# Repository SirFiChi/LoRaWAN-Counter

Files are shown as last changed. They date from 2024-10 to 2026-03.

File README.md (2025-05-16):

# LoRaWAN-Counter V1.0
Digitaler Zutrittszähler für die Statistik der Münchner Stadtbibliothek
und für den digitalen Zwilling der LHM

Bei diesem Projekt handelt es sich um eine kostengünstige Lösung einfache Daten per LoRaWAN an das TTN zu senden, um diese für andere Dienste, in diesem Fall den digitalen Zwilling der LHM, bereitstellen zu können.

Als Pilotprojekt dient die bereits "analoge" Zählung der Besucher*Innen der Münchner Stadtbibliotheken. Diese werden mit einer Lichtschranke und einem Zählwerk erfasst. Um die Daten nicht ablesen und manuell übermitteln zu müssen, soll eine einfache technische Lösung umgesetzt werden, die den Einsatz des Personals ablöst.

---
## Ablauf
Der geplante Ablauf des Codes:

* Initialisierung der Komponenten
* Abfrage ob Jumper gesetzt sind (für Dividierung z.B. durch zwei, wenn Eingang gleich Ausgan, oder durch vier, wenn die Lichtschranke zu Tief hängt und Beine und nicht Hüften zählt. Ggf. auch einen Verbose Modus für das Display, um z.B. Signalstärke zu messen).
* Zugriff auf Speicher ob bereits ein Wert gespeichert wurde und zu diesem addieren.
* Zählen der Auslösungen an der Lichtschranke.
* Übermitteln der Daten alle X Minuten an das TTN. (Ggf. auch per Jumper anpassbar. Im Fall der MSB ist alle sechs Minuten angedacht.)

---
## Hardware
* Microcontroller: Basis ist ein "ESP32 LoRa V3" mit SX1262 Chip (863-928MHz) als Original der Firma Heltec oder rebranded.
* Gehäuse: Die Firma Mollom bietet absperrbare Gehäuse, die zwar keinen 100%igen Schutz vor Manipulation bieten, aber die Komponenten schützen und Manipulation sichtbar machen.
* Daten-Speicher:interner Speicher ades ESP32

Für einen Prototypen werden folgende Komponenten getestet:
* https://www.amazon.de/gp/product/B0CKRGVLK4 (ESP32 LoRa V3)
* https://www.amazon.de/gp/product/B09XJZ6WGT (Gehäuse)
* https://www.amazon.de/gp/product/B077JYCD18 (Lichtschranke)
* https://www.amazon.de/gp/product/B07BDTMZQ6 (Netzteil 5V/3A)
* https://www.amazon.de/gp/product/B06XWSYRCF (Netzteil 12V/1,25A)
* https://www.amazon.de/gp/product/B0CYLPM7T7 (Kabeldurchführungen)
* ESP32-Hutschienen-Gehäuse für den ESP32 ist eine Eigenentwicklung

---
## Software
* Es wird die Arduino IDE verwendet, um einen einfachen Einstieg zu gewährleisten, um auf mehr Ressourcen zugreifen zu können und um das Projekt möglichst einfach reproduzierbar zu machen.
* In den Dateien wird auf die Herkunft von Fremdcode hingewiesen.
* Um den Versand alle X Minuten durchzuführen, während die Zählung weiterläuft, wurde das Skript LoRaWAN_TTN.ino von Rop Gonggrijp (ropg) und mein erster Versuch gekreuzt
* Ich bin kein Software-Entwickler. Was nach "Quick'n'Dirty" aussieht ist nur Dirty. Verbesserungsvorschläge werden gerne angenommen.

---
## Sicherheit
* Als Übertragungsmittel wurde LoRaWAN gewählt, damit die Datenübertragung nicht durch die Infrastruktur der LHM läuft. Die Daten werden an das TTN übermittelt, und dort abgegriffen.
* Die übertragenen Daten sind "Referat", "DeviceID", "Teiler" des Messwertes, "Zähler1", "Zähler2" und den "Gesamtzähler" (die Addition der beiden Zähler). Es werden also keine personenbezogennen oder sicherheitsrelevanten Daten übermittelt!
* Durch die sehr geringe Relevanz der Datensicherheit ist eine unverschlüsselte Datenübertragung zu einem Drittanbieter nicht von Bedeutung.
* Auch wenn der Quellcode über GitHub veröffentlicht wurde, ist eine Manipulation der Daten am Sender erst möglich, wenn der Mikrokontroller entwendet wird. Die Zugangsdaten zum TTN (AppEUI, DevEUI, DEVKEY) müssen hierfür ausgelesen werden.
* Der Sender selbst wird in einem absperrbaren Gehäuse verbaut. Manipulation am Gehäuse wird wahrgenommen.

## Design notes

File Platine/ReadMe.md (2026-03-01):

Gedruckte Platine für den LoRaWAN-Counter in einem neuen, eigenständigen Gehäuse.
J1 - Impulsgeber 1
J2 - Impulsgeber 2
J3 - Jumper für Teilung und Reset (Ohne = 1:1 || 1+2 = 1/2 || 2+3 = 1/4 || 1+2+3 = Reset)
J4 - 5V | 3.3V | Ground

Screenshots & Gerber-Datei für https://jlcpcb.com

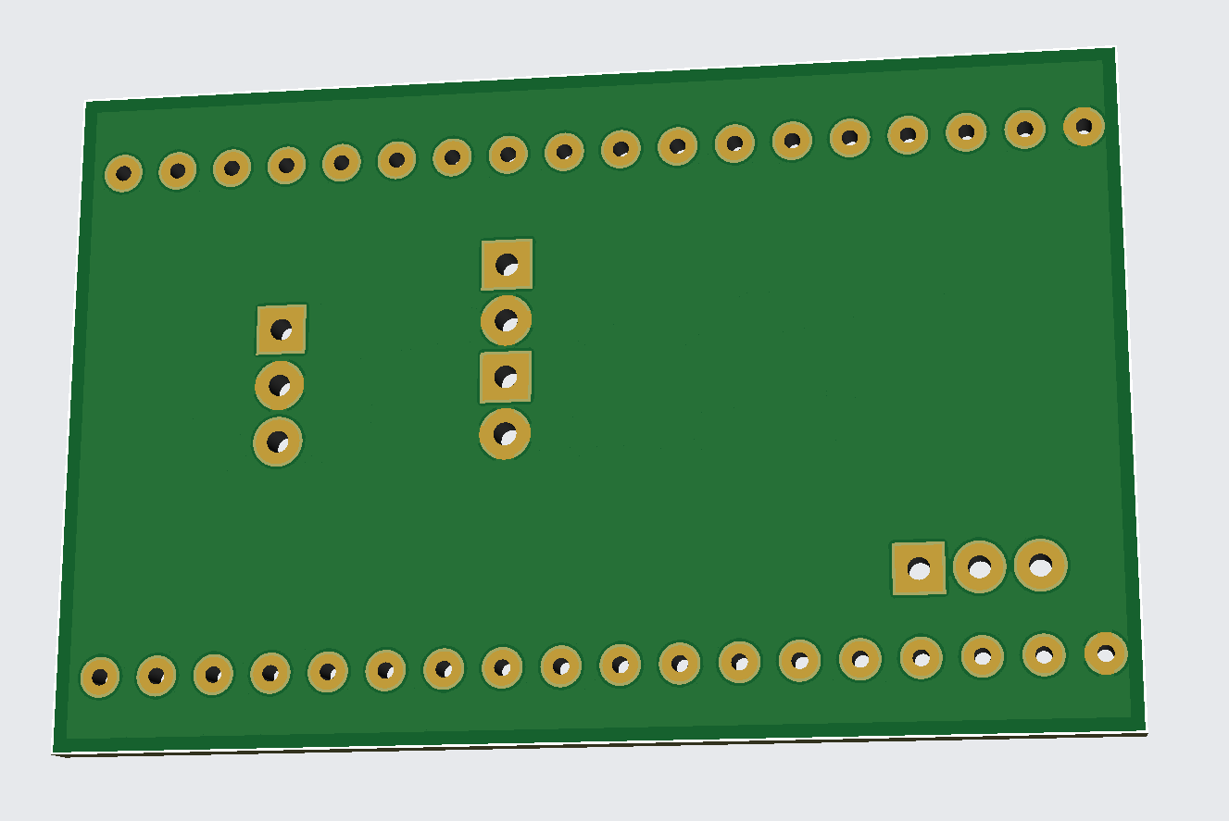
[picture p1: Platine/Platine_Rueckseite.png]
Platine Rückseite


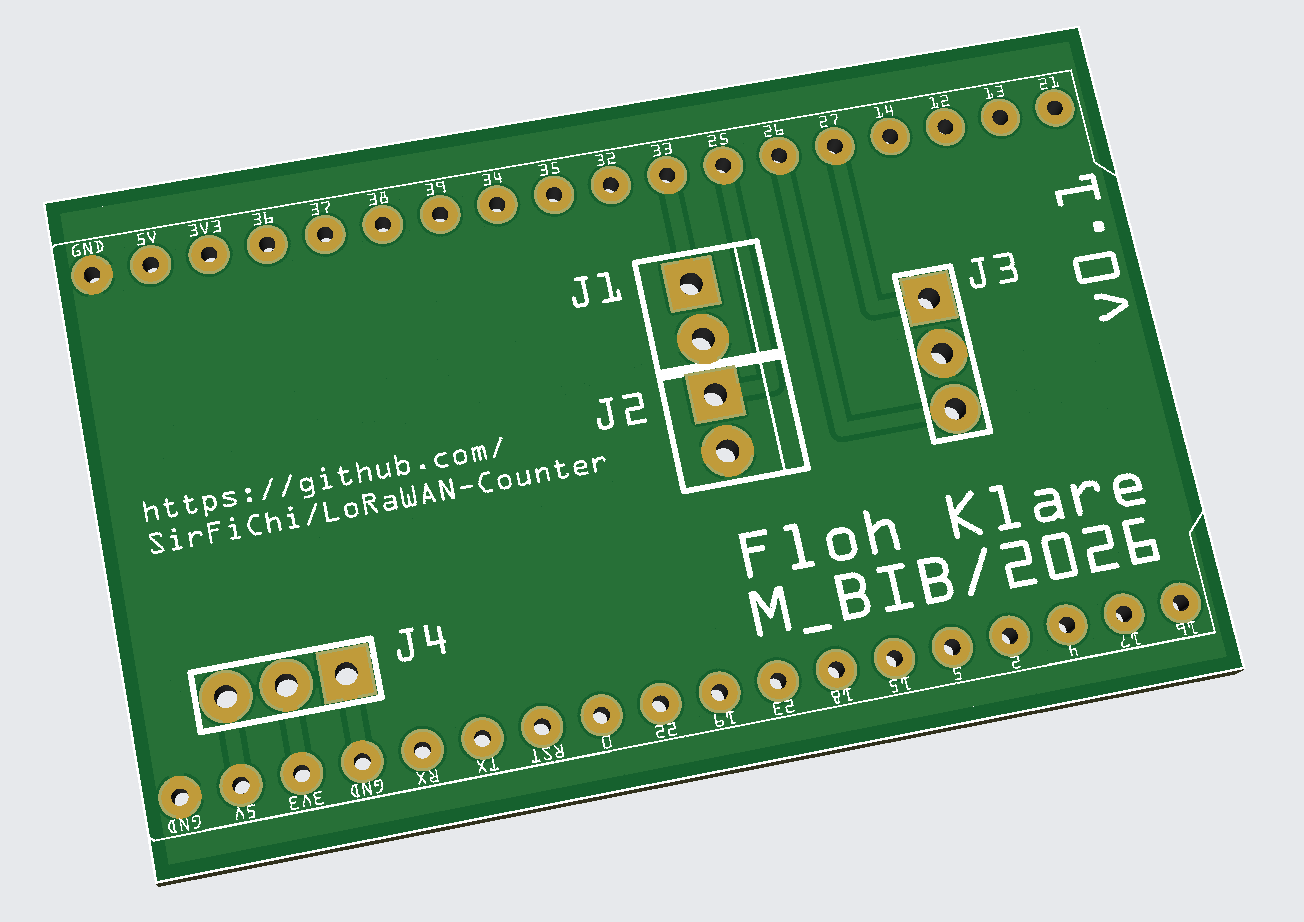
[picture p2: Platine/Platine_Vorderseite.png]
Platine Vorderseite


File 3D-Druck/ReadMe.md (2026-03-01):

Original: WiFi LoRa 32 (V4)(Heltec V4) (https://www.printables.com/model/1460633-wifi-lora-32-v4heltec-v4) von Adi CEvil // @AdiCEvil_3819894

Angepasst mit Tinkercad (https://www.tinkercad.com/).

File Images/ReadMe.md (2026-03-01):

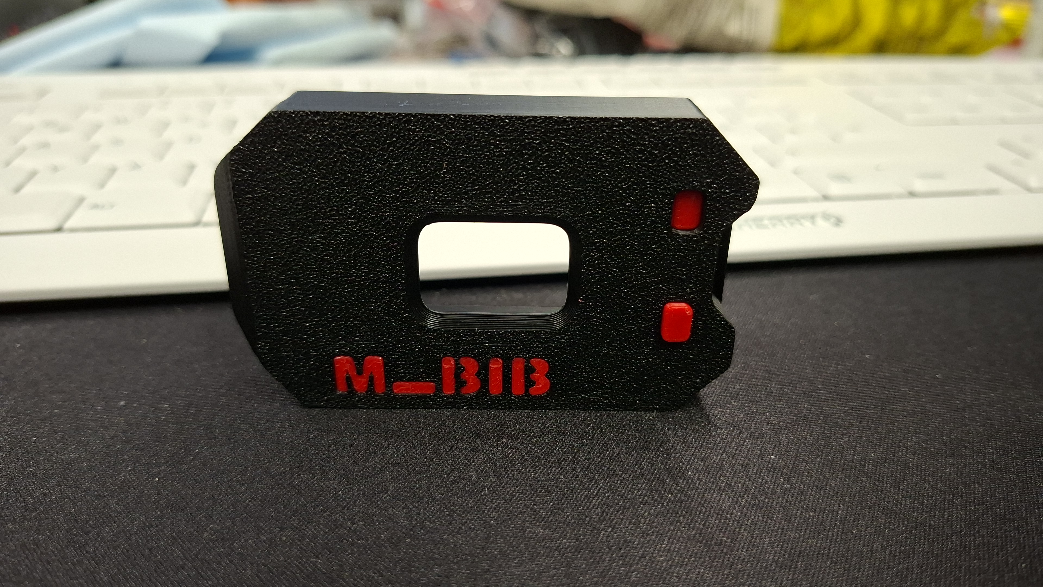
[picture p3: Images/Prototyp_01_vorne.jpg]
Protoyp offen von vorne


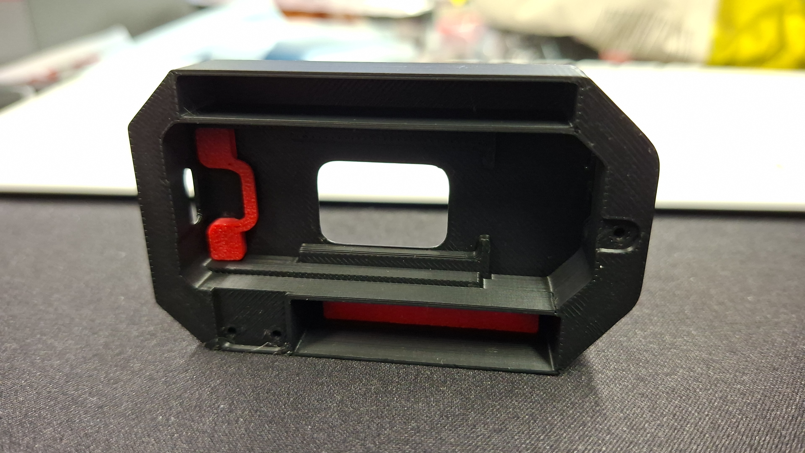
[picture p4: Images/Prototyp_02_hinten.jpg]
Protoyp offen von hinten


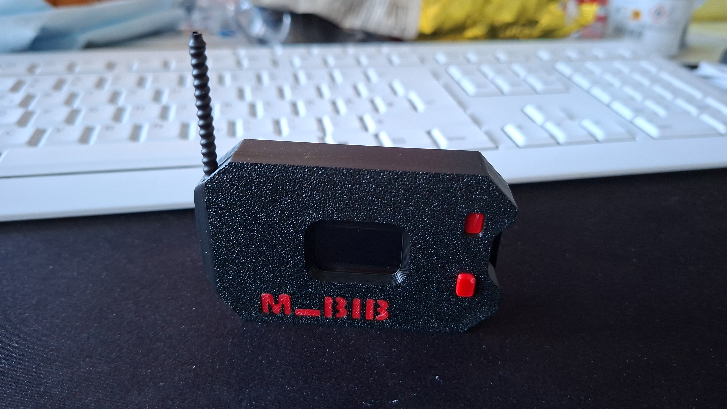
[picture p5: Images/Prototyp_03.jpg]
Protoyp von vorne mit ESP32


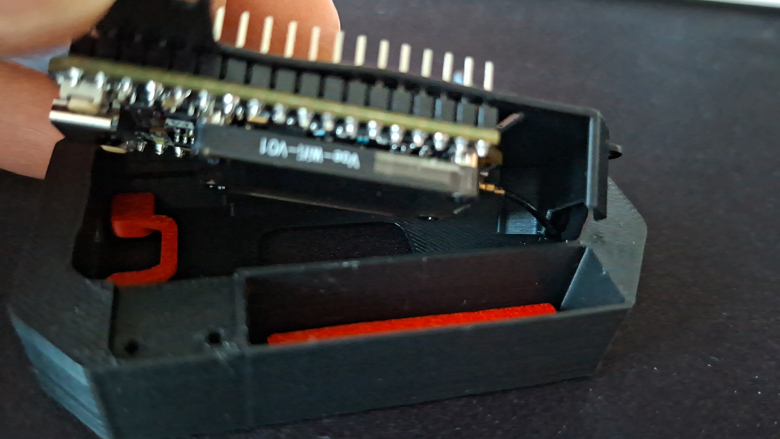
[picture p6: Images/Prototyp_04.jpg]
Protoyp mit angeschlossener Antenne


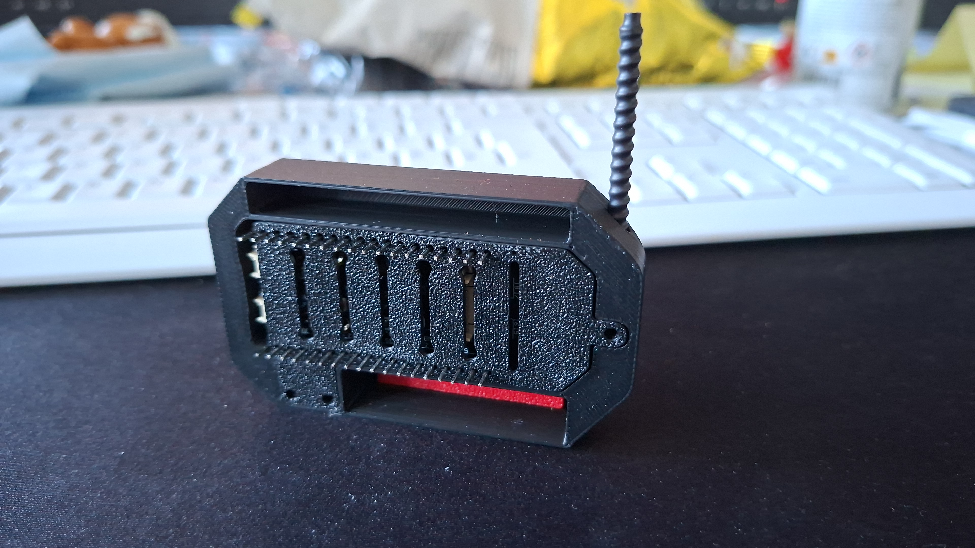
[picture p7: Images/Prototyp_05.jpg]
Protoyp mittlerer Deckel


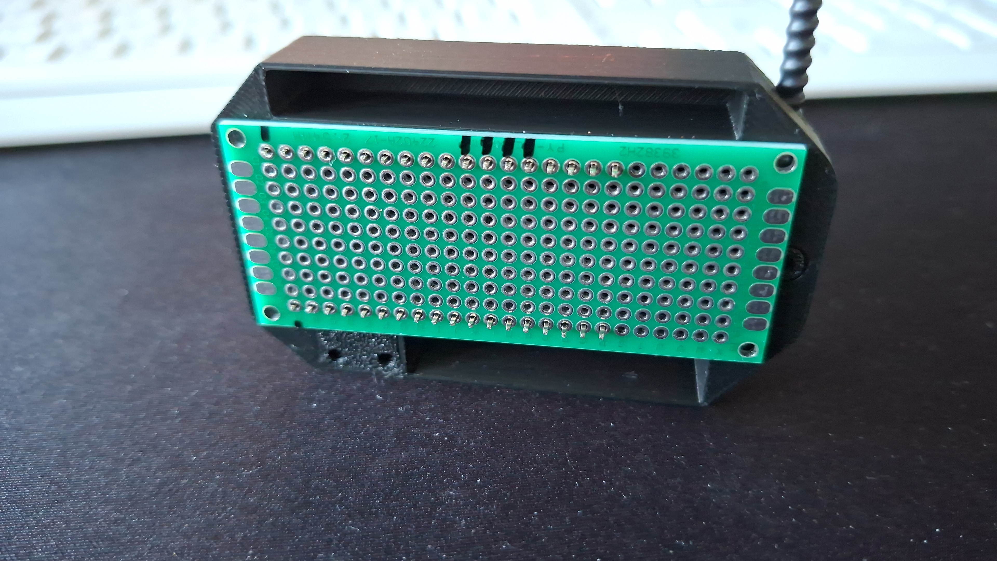
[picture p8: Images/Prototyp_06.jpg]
Protoyp mit Lochrasterplatte


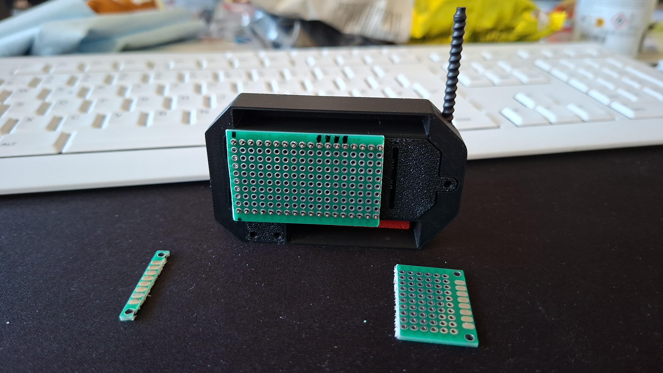
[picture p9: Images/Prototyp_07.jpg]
Protoyp mit Lochrasterplatte gekürzt


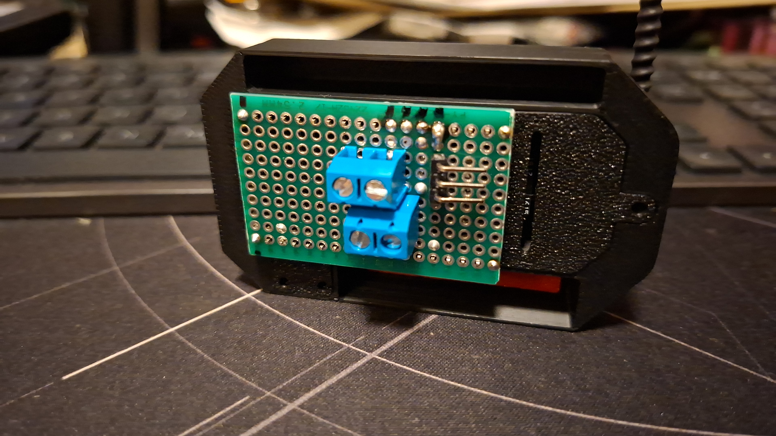
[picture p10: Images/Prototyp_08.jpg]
Protoyp mit Lochrastertaste gelötet


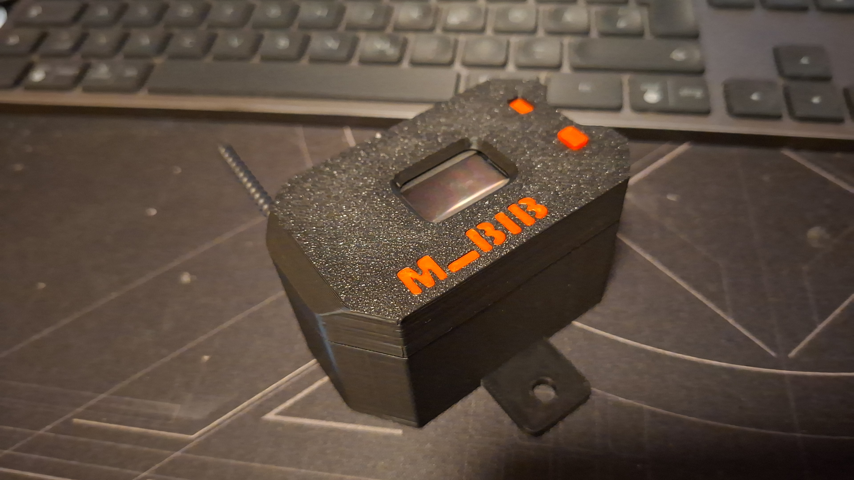
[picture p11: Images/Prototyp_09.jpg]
Protoyp mit Unterteil von vorne


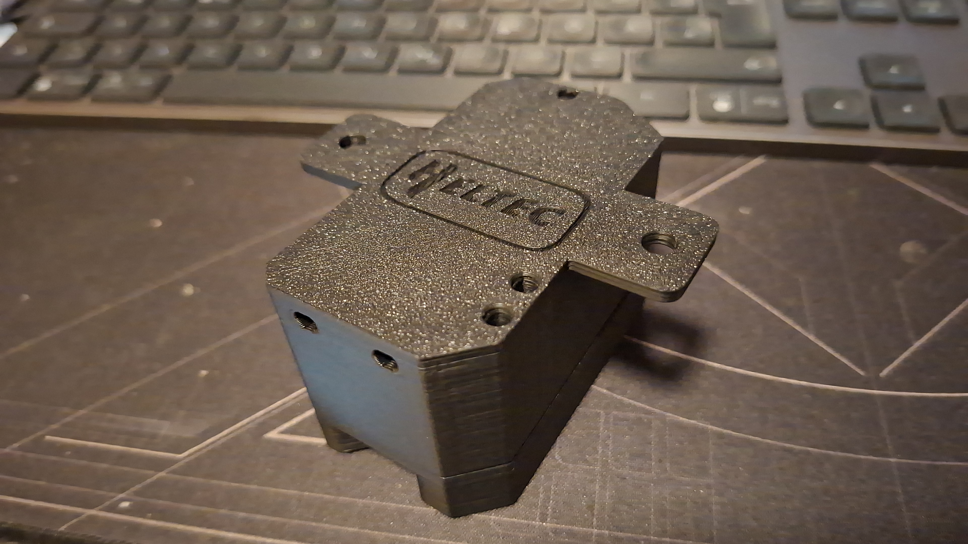
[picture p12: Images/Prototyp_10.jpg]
Protoyp mit Unterteil von hinten


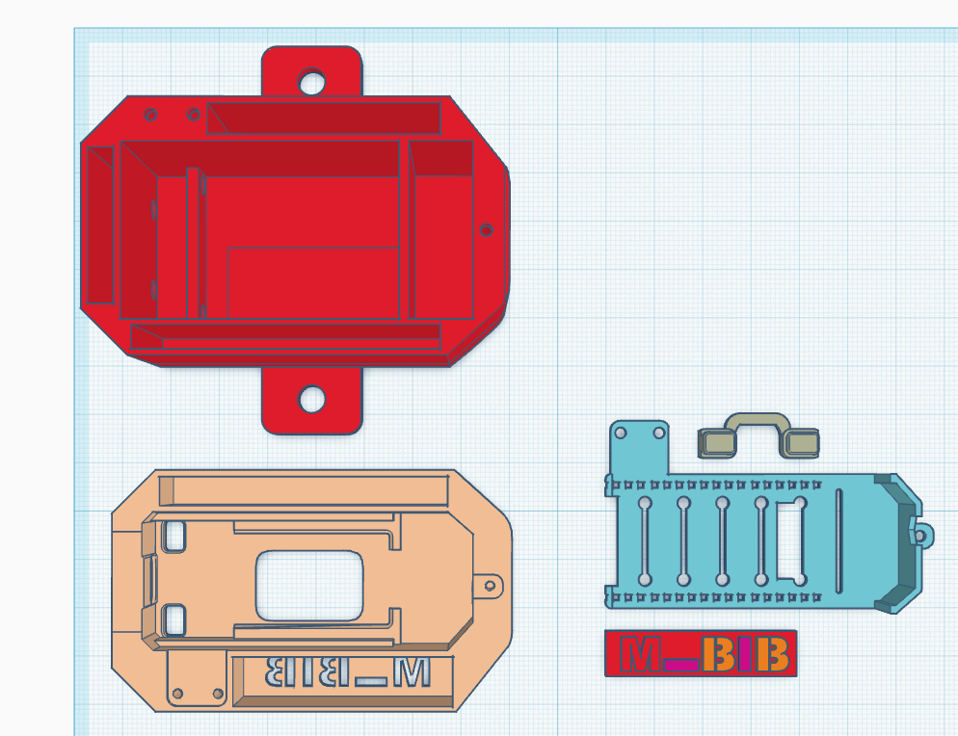
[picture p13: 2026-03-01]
Images/Prototyp_00.PNG

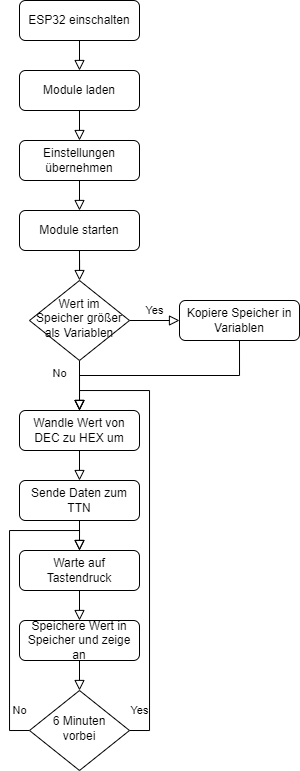
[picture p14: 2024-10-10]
Images/LoRaWan_ESP32_LoRa_v3.drawio.png

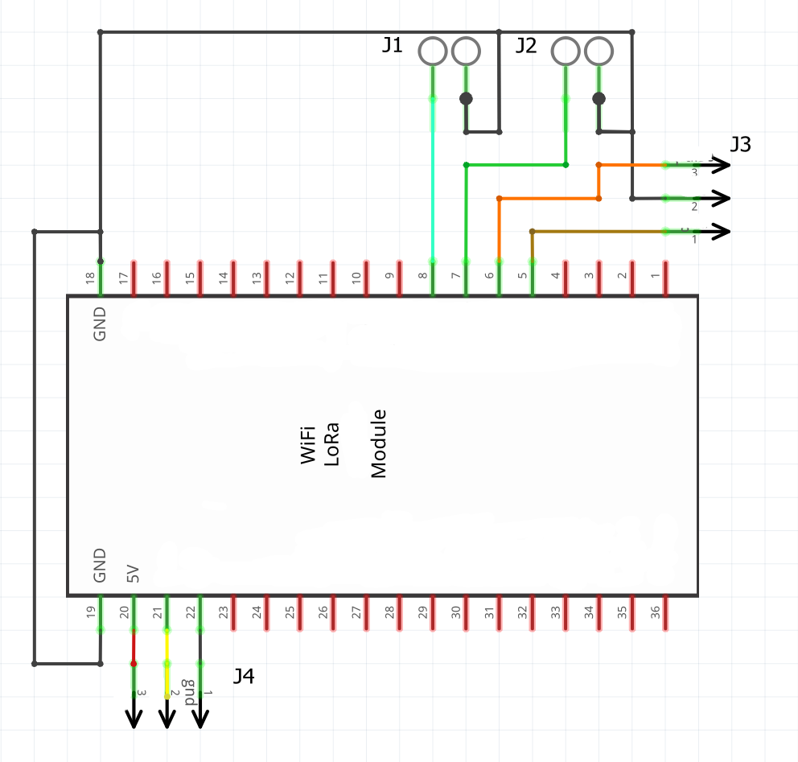
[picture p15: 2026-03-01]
Images/Schaltplan.png

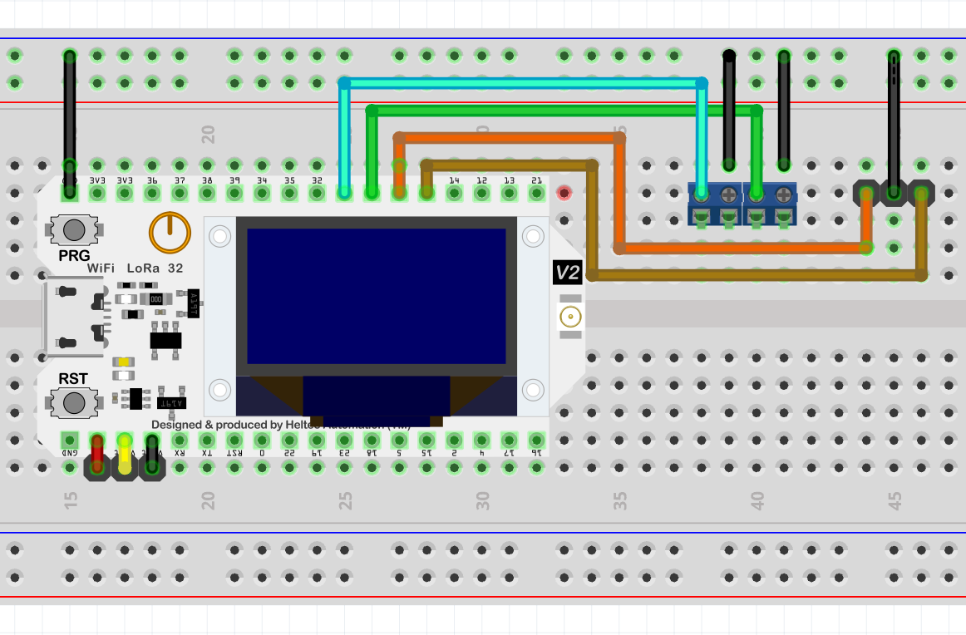
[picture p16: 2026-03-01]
Images/Steckplatine.png

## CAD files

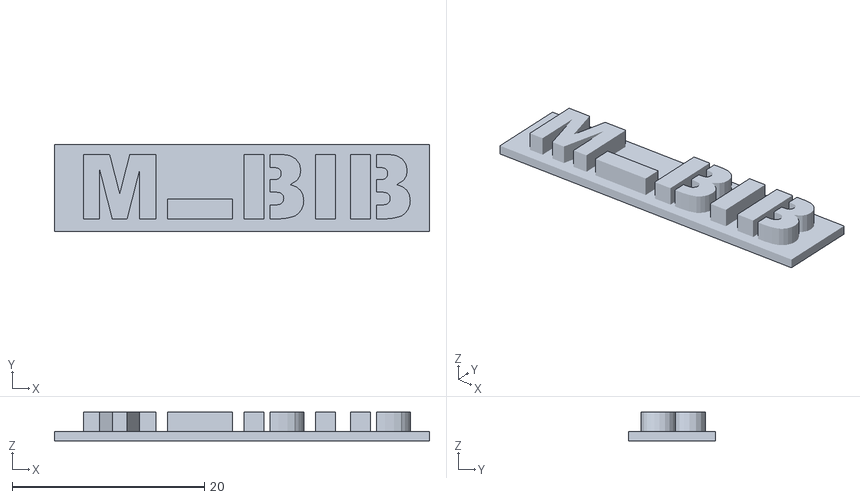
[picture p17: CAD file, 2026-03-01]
3D-Druck/MSB_Heltec_v4_Bewegungsmelder_MBIB.stl
39.0 x 9.00 x 3.00

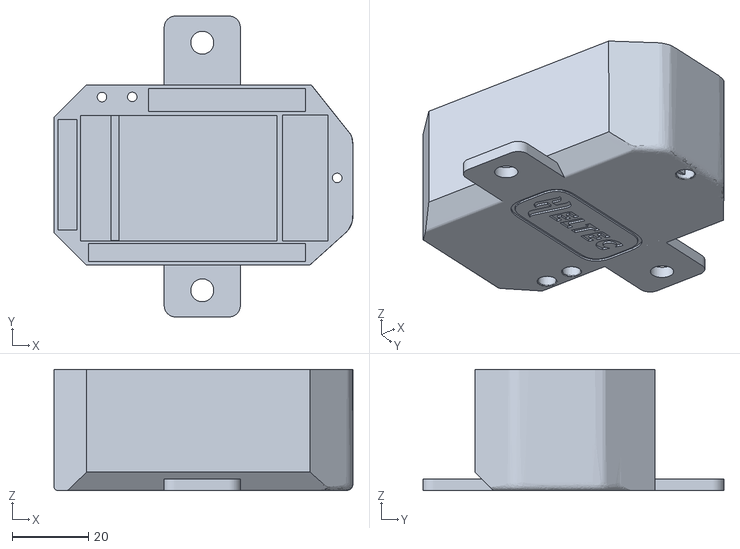
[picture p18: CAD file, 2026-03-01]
3D-Druck/MSB_Heltec_v4_Bewegungsmelder_unten.stl
78.5 x 79.0 x 31.8

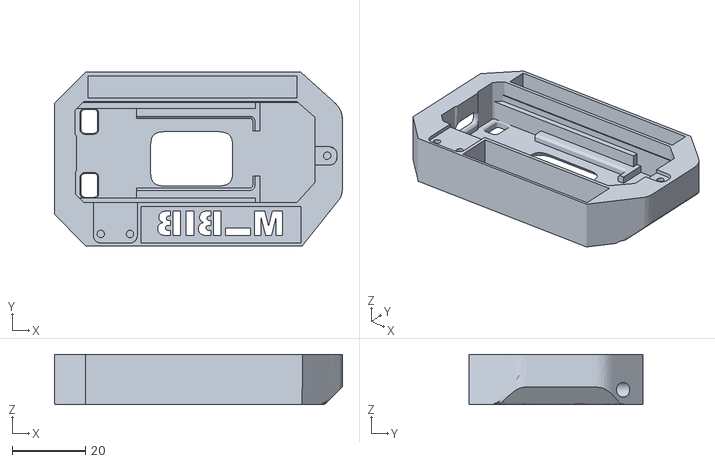
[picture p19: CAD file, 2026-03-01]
3D-Druck/MSB_Heltec_v4_Bewegungsmelder_oben.stl
78.5 x 47.3 x 13.7

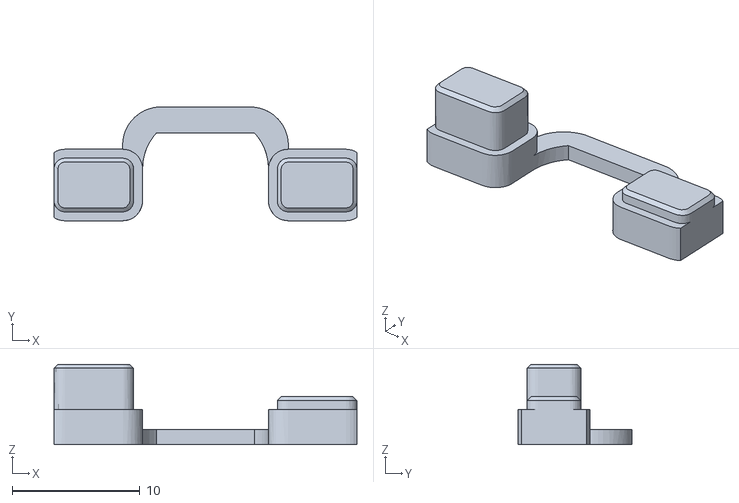
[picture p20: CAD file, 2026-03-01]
3D-Druck/MSB_Heltec_v4_Bewegungsmelder_Knöpfe.stl
23.7 x 8.89 x 6.28

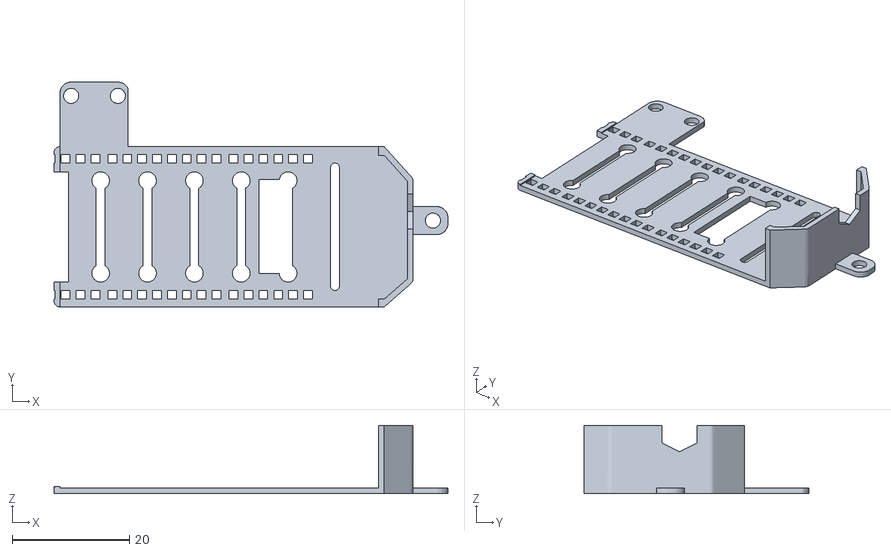
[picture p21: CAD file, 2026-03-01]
3D-Druck/MSB_Heltec_v4_Bewegungsmelder_mitte.stl
67.2 x 38.4 x 11.7

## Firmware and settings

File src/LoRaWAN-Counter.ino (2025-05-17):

/**********
 *
 * LoRaWAN-Counter v1.0
 *
 **********
 *
 * LHM - KULT-BIB-G4
 *
 **********
 * 
 * Zählt die Auslösung an bis zu zwei Kontakten (z.B. per Lichtschranke), speichert diese auf dem ESP32
 * und überträgt die Zählung zum TTN.
 * Wird der Controller vom Strom getrennt und wieder eingeschaltet, wird der Wert aus dem Speicher
 * geholt und weiter gezählt.
 * Über Jumper lässt sich einstellen ob die Werte "1:1", halbiert oder geviertelt übergeben werden sollen.
 * (Wenn z.B. der Eingang auch ein Ausgang ist und somit Personen doppelt zählen würde, und/oder die
 * Lichtschranke so tief hängt, dass Beine und nicht Personen gezählt werden.)
 * Der Faktor kann nur für die gesamte Einheit, nicht individuell für die Kontakte, gesetzt werden.
 * 
 **********
 *
 * Die Daten für das TTN werden bei der ersten Nutzung des Skripts im seriellen Monitor abgefragt und eingegeben.
 * Siehe: https://github.com/ropg/LoRaWAN_ESP32
 * Diese Daten können in der Arduino IDE über "Erease all flash before sketch upload" zurückgesetzt werden.
 *
 **********
 *
 * Floh Klare
 * https://github.com/SirFiChi/LoRaWAN-Counter
 *
 **********
 *
 * !!!!!!!!!!!!!!!!!!!!!!!!!!!!!!!!!!!!!!!!!!!!!!!!!!!!!!!!!!!!!!!!!!!!!!!!!!!!!!!!!!!!!!!!!!!!!!!!!!!!!!!!!!!!!!!!!!
 *   Die Boardtreiber esp32 von Espressif Systems in der Version 3.2.0 sind defekt und verhindern das Komplieren!!!
 * !!!!!!!!!!!!!!!!!!!!!!!!!!!!!!!!!!!!!!!!!!!!!!!!!!!!!!!!!!!!!!!!!!!!!!!!!!!!!!!!!!!!!!!!!!!!!!!!!!!!!!!!!!!!!!!!!!
 *
 **********
 *
 * HINWEIS: Die Lebensdauer des Speichers ist begrenzt. Sollte ein Bereich defekt sein, kann eine andere Adresse verwendet werden.
 *
**********/


/**/
/* DEBUG-Nachrichten aktivierbar, um den Ablauf zu verstehen und Problemquellen einzukreisen */
/**/
int DEBUG = 1;                                                      // DEBUG-Modus, 1=an, 0= aus
  

/**/
/* Definiert eine minimale Wartezeit, um die Richtlinien des TTN einzuhalten */
/**/
#define MINIMUM_DELAY 120                                           // Setzt das minimale Wartezeit auf 120 Sekunden


/**/
/* Module für Funktionalität und Hardware laden */
/**/
#include "module.h"                                                 // Hier gibt es nichts zu konfigurieren, außer es werden andere Komponenten verwendet.


/**/
/* KONFIGURATION der zuvor geladenen Module  */
/**/
#include "modulconfig.h"                                            // Die Grundkonfiguration der Module. Hier ist nur das Sende-Interval relevant.


/**/
/* Definiere und befülle ein paar globale Variablen */
/**/
  #include "config.h"                                               // !!! Hier werden die individuellen Einstellungen gesetzt !!!
  boolean initLoRaWANonce = false;                                  // Hilfsvariable, damit die Initialisierung des Aufbaus zum TTN nur einmal stattfindet
  boolean runLoRaWAN = false;                                       // Hilfsvariable, damit bereits nach dem Einschalten Messdaten gesendet werden, und nicht erst nach Ablauf der Zeit
  unsigned int eeAddress0esp = 0;                                   // Initialisiere die Variable "eeAddress" als int und setze sie auf 0 (für Speicherort 0 im EEPROM)
  unsigned int eeAddress1esp = 4;                                   // Initialisiere die Variable "eeAddress" als int und setze sie auf 0 (für Speicherort 4 im EEPROM)
  unsigned int eeAddressallesp = 8;                                 // Initialisiere die Variable "eeAddress" als int und setze sie auf 0 (für Speicherort 8 im EEPROM)
  unsigned long count1 = 0;                                         // für Kontakt 1
  unsigned long count2 = 0;                                         // für Kontakt 2
  unsigned long countall = count1 + count2;                         // Addition der beiden Kontakte
  unsigned long count1esp = 0;                                      // für Kontakt 1 auf dem ESP32
  unsigned long count2esp = 0;                                      // für Kontakt 2 auf dem ESP32
  unsigned long countallesp = count1esp + count2esp;                // Addition der beiden Kontakte auf dem ESP32
  unsigned long count1real = 0;                                     // für Kontakt 1
  unsigned long count2real = 0;                                     // für Kontakt 2
  unsigned long countallreal = 0;                                   // Addition der beiden Kontakte
  unsigned long count1Show = 0;                                     // für Kontakt 1
  unsigned long count2Show = 0;                                     // für Kontakt 2
  unsigned long countallShow = 0;                                   // Addition der beiden Kontakte
  uint32_t count1Trans = count1Show;                                // für Kontakt 1
  uint32_t count2Trans = count2Show;                                // für Kontakt 2
  uint32_t countallTrans = countallShow;                            // für beide Kontakte
  unsigned long teiler;                                             // Wert durch den die Zählung geteilt wird
  unsigned long previousMillis = 0;                                 // Für die Zeitsteuerung zum Versand des PayLoads
  const long sendinterval = funkInterval * 60 * 1000;               // Rechnet das Sendeinterval in Millisekunden um

/**/
/* Funktionen um das Display zu steuern */
/**/
 #include "display.h"                                               // Funktionen zum de-/aktivieren und Resetten des Displays. Hier gibt es nichts zu konfigurieren.



void setup() {
  if (DEBUG == 1){Serial.println("DEBUG-Modus ist eingeschaltet.");}
  if (DEBUG == 1){Serial.println("DEBUG: Die Module wurden geladen.");}
  if (DEBUG == 1){Serial.println("DEBUG: Die Module wurden konfiguriert.");}
  if (DEBUG == 1){Serial.println("DEBUG: Die Variablen wurden angelegt.");}
  if (DEBUG == 1){Serial.println("DEBUG: Die Funktionen für die (De-)Aktivierung des Displays wurden eingebunden.");}

  Serial.begin(115200);                                             // Setze die serielle Geschwindigkeit auf 115200 baud (für serielle Konsole)
  heltec_setup();

  VextON();                                                         // Schaltet das Display ein, wichtig für Version V3.2 des Boards
  displayReset();                                                   // Resetet das Display, wichtig für Version V3.2 des Boards
  display.init();                                                   // Initialisiert das Display
  display.setFont(ArialMT_Plain_10);                                // Setzt die Standardschrift und -größe für das Display

  button1.setDebounceTime(50);                                      // Setzt die Nachfederunterdrückung des Kontakt1 auf 50ms, damit das Schließen des Kontakts nur einmal gezählt wird
  button1.setCountMode(COUNT_FALLING);
  button2.setDebounceTime(50);                                      // Setzt die Nachfederunterdrückung des Kontakt2 auf 50ms, damit das Schließen des Kontakts nur einmal gezählt wird
  button2.setCountMode(COUNT_FALLING);

  Wire.begin();                                                     // Initialisiert die Verbindung zum I2C als Master
  pinMode(20, INPUT_PULLUP);                                        // Definiert Port 20 als Pullup Input
  pinMode(26, INPUT_PULLUP);                                        // Definiert Port 26 als Pullup Input
  int jumper0 = digitalRead(20);                                    // Liest Status von Jumper 0 an Port 20
  int jumper1 = digitalRead(26);                                    // Liest Status von Jumper 1 an Port 26
  if (DEBUG == 1){
    Serial.print("Jumper 0 ist gesetzt auf: ");
    Serial.println(jumper0);
    Serial.print("Jumper 1 ist gesetzt auf: ");
    Serial.println(jumper1);
    Serial.println("(0 = Jumper gesteckt, 1 = Jumper nicht gesteckt)");
  }
  while ((jumper0 == 0) && (jumper1 == 0)){                         // Wenn Jumper 0&1 überbrückt...
    #include "reset.h"                                              // ...inkludiere reset.h um beim Booten die Werte im Speicher zu löschen.
    if (DEBUG == 1){Serial.println("DEBUG: Da beide Jumper überbrückt wird der Speicher gelöscht.");}
  }
  #include "jumper.h"                                               // Inkludiert die ausgelagerte Jumper-Abfrage


  EEPROM.begin(EEPROM_SIZE);                                        // Initialisiere den EEPROM auf die Größe
  if (DEBUG == 1){Serial.println("DEBUG: Speicher initialisiert mit definierter Größe.");}
  count1esp = EEPROM.get( eeAddress0esp, count1esp );               // Rufe den gespeicherten Wert vom EEPROM ab und fülle damit "count1esp"
  count2esp = EEPROM.get( eeAddress1esp, count2esp );               // Rufe den gespeicherten Wert vom EEPROM ab und fülle damit "count2esp"
  countallesp = EEPROM.get( eeAddressallesp, countallesp );         // Rufe den gespeicherten Wert vom EEPROM ab und fülle damit "countallesp"
  if (DEBUG == 1){Serial.println("DEBUG: Die Werte wurden aus dem Speicher abgerufen.");}

 /**/
 /* Gibt die Willkommensnachrichten des Startbildschirms aus */
 /**/
  #include "startscreen.h"                                          // Inkludiert die ausgelagerte Ausgabe des Startbildschirms


 /**/
 /* Diverse DEBUG-Ausgaben am Ende von setup() */
 /**/  
  if (DEBUG == 1){Serial.println("DEBUG: Der Startscreen wurde am Display dargestellt.");}
  if (DEBUG == 1){Serial.println("DEBUG: setup() abgeschlossen.");}
  if (DEBUG == 1){Serial.print("DEBUG: Aktuelle Systemzeit in Millis: ");}
  if (DEBUG == 1){Serial.println(millis());}                        // Gibt die aktuelle Laufzeit "millis()" aus
}



void loop() {
 /**/
 /* Abfragen der Kontakte der Jumper, für die Verarbeitung als Teiler oder den Reset der Zählung */
 /**/
  int jumper0 = digitalRead(20);                                    // Liest Status von Port 20
  int jumper1 = digitalRead(26);                                    // Liest Status von Port 26


 /**/
 /* Erkennen der Kontakte als "Buttons" */
 /**/
  button1.loop();                                                   // Die notwendige Loop-Funktion für den ersten Kontakt
  button2.loop();                                                   // Die notwendige Loop-Funktion für den zweiten Kontakt
    unsigned long count1real = button1.getCount() + count1esp;      // für Kontakt 1
    unsigned long count2real = button2.getCount() + count2esp;      // für Kontakt 2
    unsigned long countallreal = count1real + count2real;           // Addition der beiden Kontakte zum Speichern
    unsigned long count1Show = count1real/teiler;                   // Erstellt Variable für den Wert der angezeigt werden soll, angepasst durch den Teiler
    unsigned long count2Show = count2real/teiler;                   // Erstellt Variable für den Wert der angezeigt werden soll, angepasst durch den Teiler
    unsigned long countallShow = count1real + count2real;           // Addition der beiden Kontakte
    uint32_t count1Trans = count1Show;                              // Erstelle Variable für den Transport über den Payload
    uint32_t count2Trans = count2Show;                              // Erstelle Variable für den Transport über den Payload
    uint32_t countallTrans = countallShow;                          // Erstelle Variable für den Transport über den Payload


/**/
/* Schreibe die Werte in das EEPROM des ESP32 */
/**/
  EEPROM.put(eeAddress0esp, count1real);                             // Schreibe den Wert aus "count1real" in den EEPROM
  EEPROM.commit();                                                   // Bestätige das Speichern in den EEPROM
  EEPROM.put(eeAddress1esp, count2real);                             // Schreibe den Wert aus "count2real" in den EEPROM
  EEPROM.commit();                                                   // Bestätige das Speichern in den EEPROM
  EEPROM.put(eeAddressallesp, countallreal);                         // Schreibe den Wert aus "countallreal" in den EEPROM
  EEPROM.commit();                                                   // Bestätige das Speichern in den EEPROM


/**/
/* Zeige die gezählten Besucher an */
/**/
  display.clear();                                                    // Displayinhalt löschen
  display.setTextAlignment(TEXT_ALIGN_LEFT);                          // Ausrichtung der Schrift ist links
  display.setFont(ArialMT_Plain_24);                                  // Schriftgröße auf 24
  display.drawString(0, 0, "Besucher:");                              // Gibt "Besucher:" an Koordinate 0,0 aus 
  display.setFont(ArialMT_Plain_16);                                  // Schriftgröße auf 16
  display.drawString(0,28, String(countallShow));                     // Gibt die Addition von count1 und count2 an Koordinate 0,28 aus 
  display.setFont(ArialMT_Plain_10);                                  // Schriftgröße auf 10
  display.drawString(0,52, "(" + String(count1Show) + "+" + String(count2Show) + ")");  // Gibt die Einzelwerte der Kontaktauslösungen, in Klammern und mit einem Plus an Koordinate 0,52 aus 
  display.display();                                                  // Befehl um die Bildausgabe zu starten


/**/
/* Integriert die ausgelagerte LoRaWAN-Funktionalität */
/**/
  #include "lorawan.h";                                               // Integriert die ausgelagerte LoRaWAN-Funktionalität


if (DEBUG == 1){Serial.println("DEBUG: loop() abgeschlossen");}
}



/**/
/* Schlafroutine, wenn keine Verbindung aufgebaut werden konnte. */
/**/
void goToSleep() {
  Serial.println("Ich gehe in den Tiefschlaf");                       // Gibt auf der Konsole aus, dass der ESP32 in den Tiefschlaf geht
  if (DEBUG == 1){Serial.println(millis());}



/**/
/* Zeige für fünf Sekunden an, dass es keinen Empfang gab und der Zähler schlafen geht. */
/**/
  display.clear();                                                    // Displayinhalt löschen
  display.setTextAlignment(TEXT_ALIGN_LEFT);                          // Ausrichtung der Schrift ist links
  display.setFont(ArialMT_Plain_16);                                  // Schriftgröße auf 16
  display.drawString(0, 0, "Kein Empfang");                           // Gibt "Kein Empfang" an Koordinate 0,0 aus 
  display.setFont(ArialMT_Plain_10);                                  // Schriftgröße auf 10
  display.drawString(0,28, "Gehe für 120 Sekunden");                  // Gibt "Gehe für 120 Sekunden" an Koordinate 0,28 aus 
  display.setFont(ArialMT_Plain_10);                                  // Schriftgröße auf 10
  display.drawString(0,52, "schlafen und starte neu.");               // Gibt "schlafen und starte neu." an Koordinate 0,52 aus 
  display.display();                                                  // Befehl um die Bildausgabe zu starten
  delay(5000);                                                        // Warte 5 Sekunden, damit man die Ausgabe lesen kann



/**/
/* Routine für den Tiefschlaf */
/**/
  persist.saveSession(node);                                          // Speichert die Session für die Nutzung nach dem Tiefschlaf
  uint32_t interval = node->timeUntilUplink();                        // Berechnet die minimale Arbeitszyklusverzögerung (gemäß FUP und Gesetz!)
  uint32_t delayMs = max(interval, (uint32_t)MINIMUM_DELAY * 1000);   // wähle das INTERVAL oder das MINIMUM_DELAY, je nachdem, was größer ist
  Serial.printf("Next TX in %i s\n", delayMs/1000);                   // Gibt auf der Konsole aus, wann der erneute Verbindungsaufbau stattfindet
  if (DEBUG == 1){Serial.println("DEBUG: ESP32 geht in den Schlafmodus durch goToSleep()");}
  delay(100);                                                         // Warte 0,1 Sekunden, damit die Nachricht vor dem DeepSleep geschrieben werden kann
  heltec_deep_sleep(delayMs/1000);                                    // Gute Nacht John Boy.
}

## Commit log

2024-10-06 Create save_unsigned_long_2_eeprom.ino
    Beispiel um einen Wert von 0 bis 4.294.967.295 in den EEPROM zu speichern und nach einem Neustart des ESP32 wieder auszulesen.
2024-10-06 Create display_add_count_-_button_press.ino
    Zeigt den Kurzschluss an zwei Pins, addiert die Anzahl der Auslösungen und addiert die Werte zu einem Gesamtergebnis.
    (Simuliert eine oder zwei Lichtschranken und gibt Einzel-und Gesamtergebnisse aus.)
2024-10-06 Create_Activate_Heltec_License.md
    Vorgang um die Lizenz auf dem ESP32 zu aktivieren.
2024-10-06 Create save_unsigned_long_2_RTC-eeprom.ino
    Beispiel um einen Wert von 0 bis 4.294.967.295 in den RTC-EEPROM zu speichern und nach einem Neustart des ESP32 wieder auszulesen.
2024-10-10 Create ChatGPT.md
    Eine Anfrage bei https://chatopenai.de/ zur Unterstützung beim Schreiben des Codes.
2024-10-10 Create LoRaWanOLED.ino
    Original Beispiel von Heltec.
    Beispiele - Heltec ESP32 Dev-Boards - LoRaWAN - LoRaWanOLED
2024-10-10 Add files via upload
    Minimalistischer/Vorläufiger Ablaufplan des Skriptes
2024-10-17 Create display_start_screens_fuer_diagnose.ino
    Einmalige Start-Screen-Folge für Diagnose-Zwecke.
    Zu addieren sind u.a.:
    * Ist die RTC angeschlossen?
    * ...
2024-10-20 Create dip_switch_test.ino
    Test um 2 Pins für "Jumper" zu verwenden.
    Kein Jumper: Einfache Zählung
    Jumper 1: Halbierte Zählung
    Jumper 2: Geviertelte Zählung
    Jumper 1+2: Setze die Zähler auf 0
2024-10-25 Create 241025-LoRaWan_ESP32_LoRa_v3.ino
    Aktueller Stand des Gesamt-Skriptes
2024-10-28 Add files via upload
    Gehäuse-Körper und Deckel für den ESP32 Lora V3.
    Der Schieber zur Fixierung an der Schiene fehlt noch.
    [ESP32_Lora_V3_RailMount_Deckel.stl, ESP32_Lora_V3_RailMount_Körper.stl]
2025-05-16 Update README.md
    Anpassung des IST-Standes mit der Fertigstellung von Version 1.0
